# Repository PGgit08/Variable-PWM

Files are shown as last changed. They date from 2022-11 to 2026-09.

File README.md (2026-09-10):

# Variable-PWM
A printed circuit board that generates a PWM signal.

## Description
### How It Works (and Specs)
Variable-PWM is a PCB that generates a PWM signal. It was designed with [Autodesk Eagle](https://www.autodesk.com/products/eagle/overview?term=1-YEAR&tab=subscription) and manufactured by [JLCPCB](https://jlcpcb.com/). It produces a pulse width modulation (PWM) square-wave signal. This signal can be modified with potentiometers **VR1** and **VR2**. **VR1** changes the signal's *frequency*, which can either range from around **0.7 HZ - 7 HZ (SLOW MODE)** or **19.7 HZ - 216.7 HZ (FAST MODE)**. Switch **S1** sets the board to **FAST MODE** if it is switched to the *left*, and it sets the board to **SLOW MODE** if it is switched to the *right*. Potentiometer **VR2** controls the signal's *duty cycle* which ranges from **0% - ~100%**. LED **D1** indicates the signal produced by the board by flashing on and off depending on the signal. **[Click here for an in-depth explanation.](/Docs/Explanation.md)**

### Board Images (Front and Back)
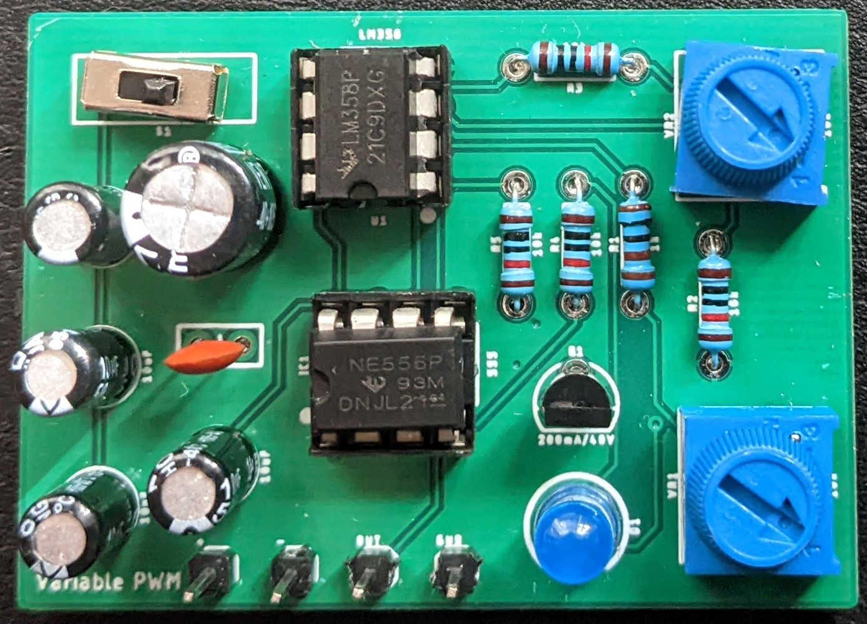
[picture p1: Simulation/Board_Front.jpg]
Board Front

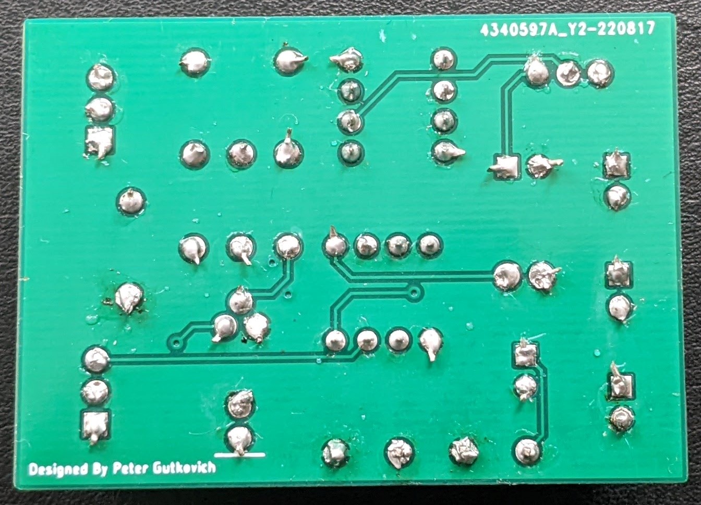
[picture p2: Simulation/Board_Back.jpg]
Board Back


## How To Use the Board
**The board should be powered with a 9V Battery.** Use the **+** and **-** pins to power the board. Use the **OUT** pin for the output signal, and the **GND** pin for connecting to the *board's* ground. Information on how to use the switch and potentiometers can be found **[here](https://github.com/PGgit08/Variable-PWM#how-it-works)**. Click **[here](/Simulation/SimVideos.md)** to see this board in action. 

## Design and Parts
### Design Hardware
The schematic and board files can be found in **[the Hardware folder](/Hardware)**. Gerber files for production are in **[this](/Production/Variable_PWM.zip)** zip folder. Also, an image of the schematic can also be seen right **[here](/Hardware/Variable_PWM.pdf)**.

### Parts Required
- LM358P Dual Operational Amplifier DIP-8 **(x1)** -> [Amazon Link](https://www.amazon.com/gp/product/B07WQWPLSP/)
- NE555 Timer DIP-8 **(x1)** -> [Amazon Link](https://www.amazon.com/gp/product/B07WR9B4JT)
- 10 uF Electrolytic Capacitor @50V (Generic) **(x4)**
- 100 uF Electrolytic Capacitor @50V (Generic) **(x1)**
- 0.1 uF Ceramic Capacitor @>9V (Generic) **(x1)**
- 10K Potentiometer **(x2)** -> [SparkFun Link](https://www.sparkfun.com/products/9806)
- DIP-8 IC Socket **(x2)** -> [SparkFun Link](https://www.sparkfun.com/products/7937)
- 10K Resistor (Generic) **(x4)** 
- 1K Resistor (Generic) **(x4)** 
- 3 Pin Slideswitch **(x1)** -> [Amazon Link](https://www.amazon.com/gp/product/B09R42XQTB)
- Male Header Pin (Generic) **(x4)**
- NPN Transistor @200mA/40V (Generic) **(x1)**
- LED @3V (Generic) **(x1)**

### **SCHEMATIC BASED ON SPARKFUN LIBRARIES -> [HERE](https://github.com/sparkfun/SparkFun-Eagle-Libraries)**

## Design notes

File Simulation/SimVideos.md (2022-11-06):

# Some Videos of the Board in Action
## **[Board Solo](https://photos.google.com/share/AF1QipOQt86xYu3LIYoZ4iMx8fBLORTxNIkFSiyrlg-VXAM1FTR-PDyvdi02ja0fbHQabA/photo/AF1QipOMZab4ttYgHVCj0UGzJjJedmy8gmi2GRmviDpl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)**
## **[Board Output Connected to NOT Gate](https://photos.google.com/share/AF1QipOQt86xYu3LIYoZ4iMx8fBLORTxNIkFSiyrlg-VXAM1FTR-PDyvdi02ja0fbHQabA/photo/AF1QipPCAgb7WWB-7l3uK8WQgtHVEI_uT10_1KNGCgFk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)**

### **NOTE: When board is in FAST MODE it looks strange in the video because the signal frequency is close to the camera's framerate**

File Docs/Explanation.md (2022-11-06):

# Variable PWM In-Depth Explanation (HAND WRITTEN)
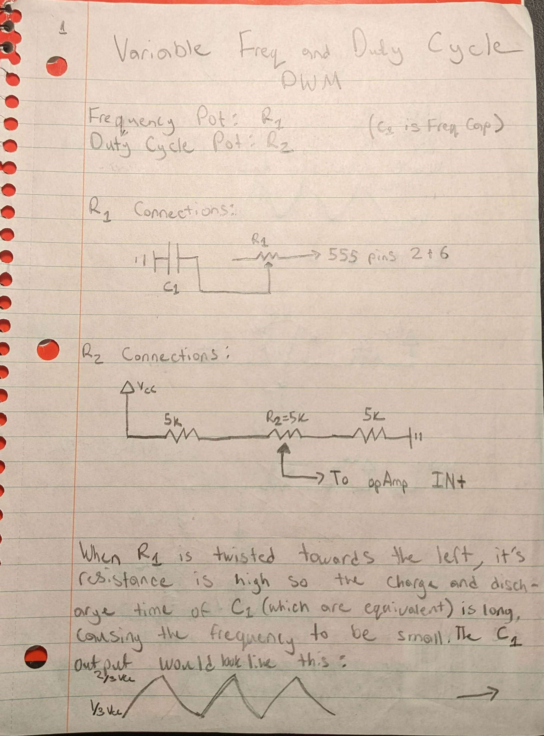
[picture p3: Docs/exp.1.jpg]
Page 1

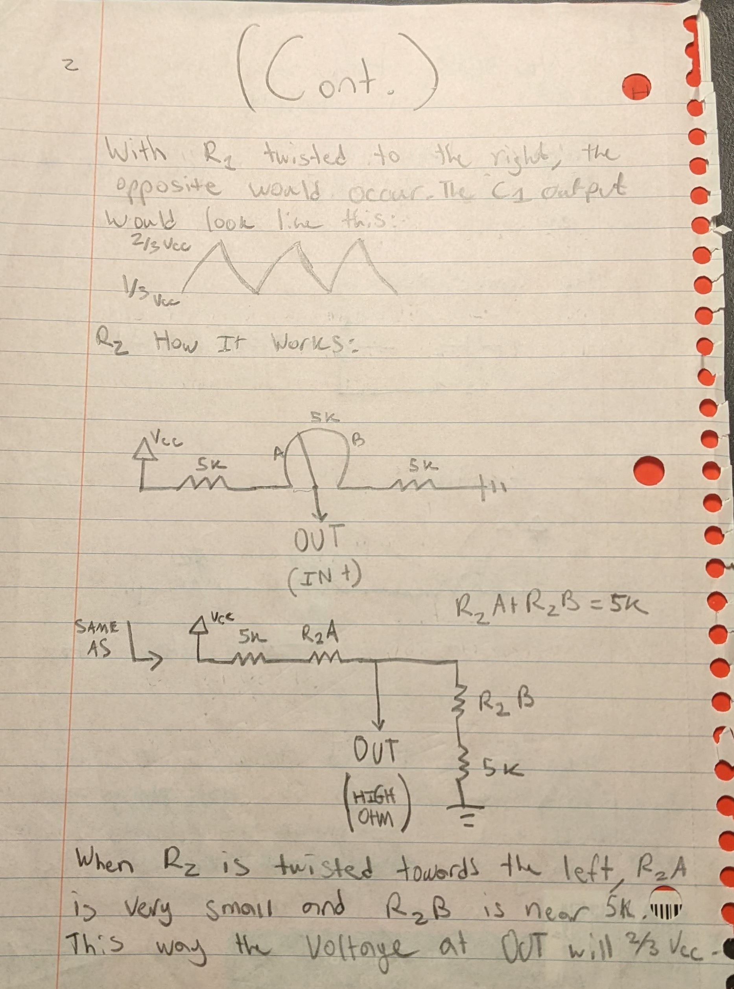
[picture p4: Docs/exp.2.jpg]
Page 2

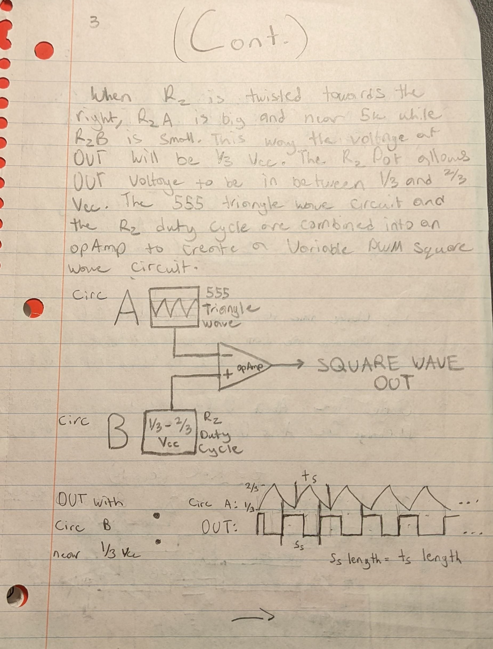
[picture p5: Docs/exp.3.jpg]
Page 3

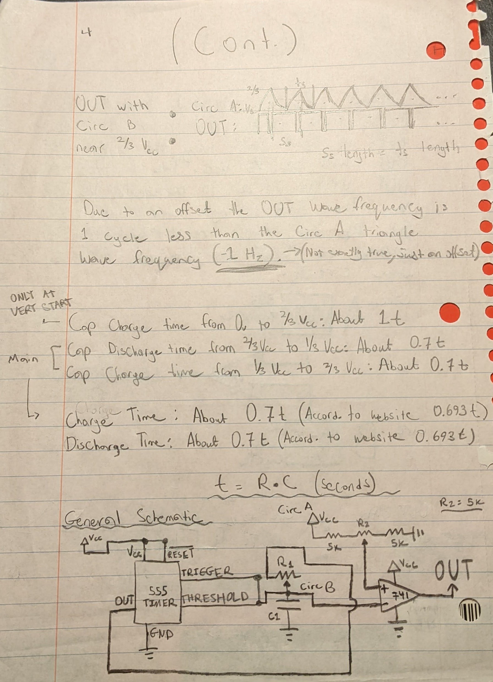
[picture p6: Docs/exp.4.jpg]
Page 4


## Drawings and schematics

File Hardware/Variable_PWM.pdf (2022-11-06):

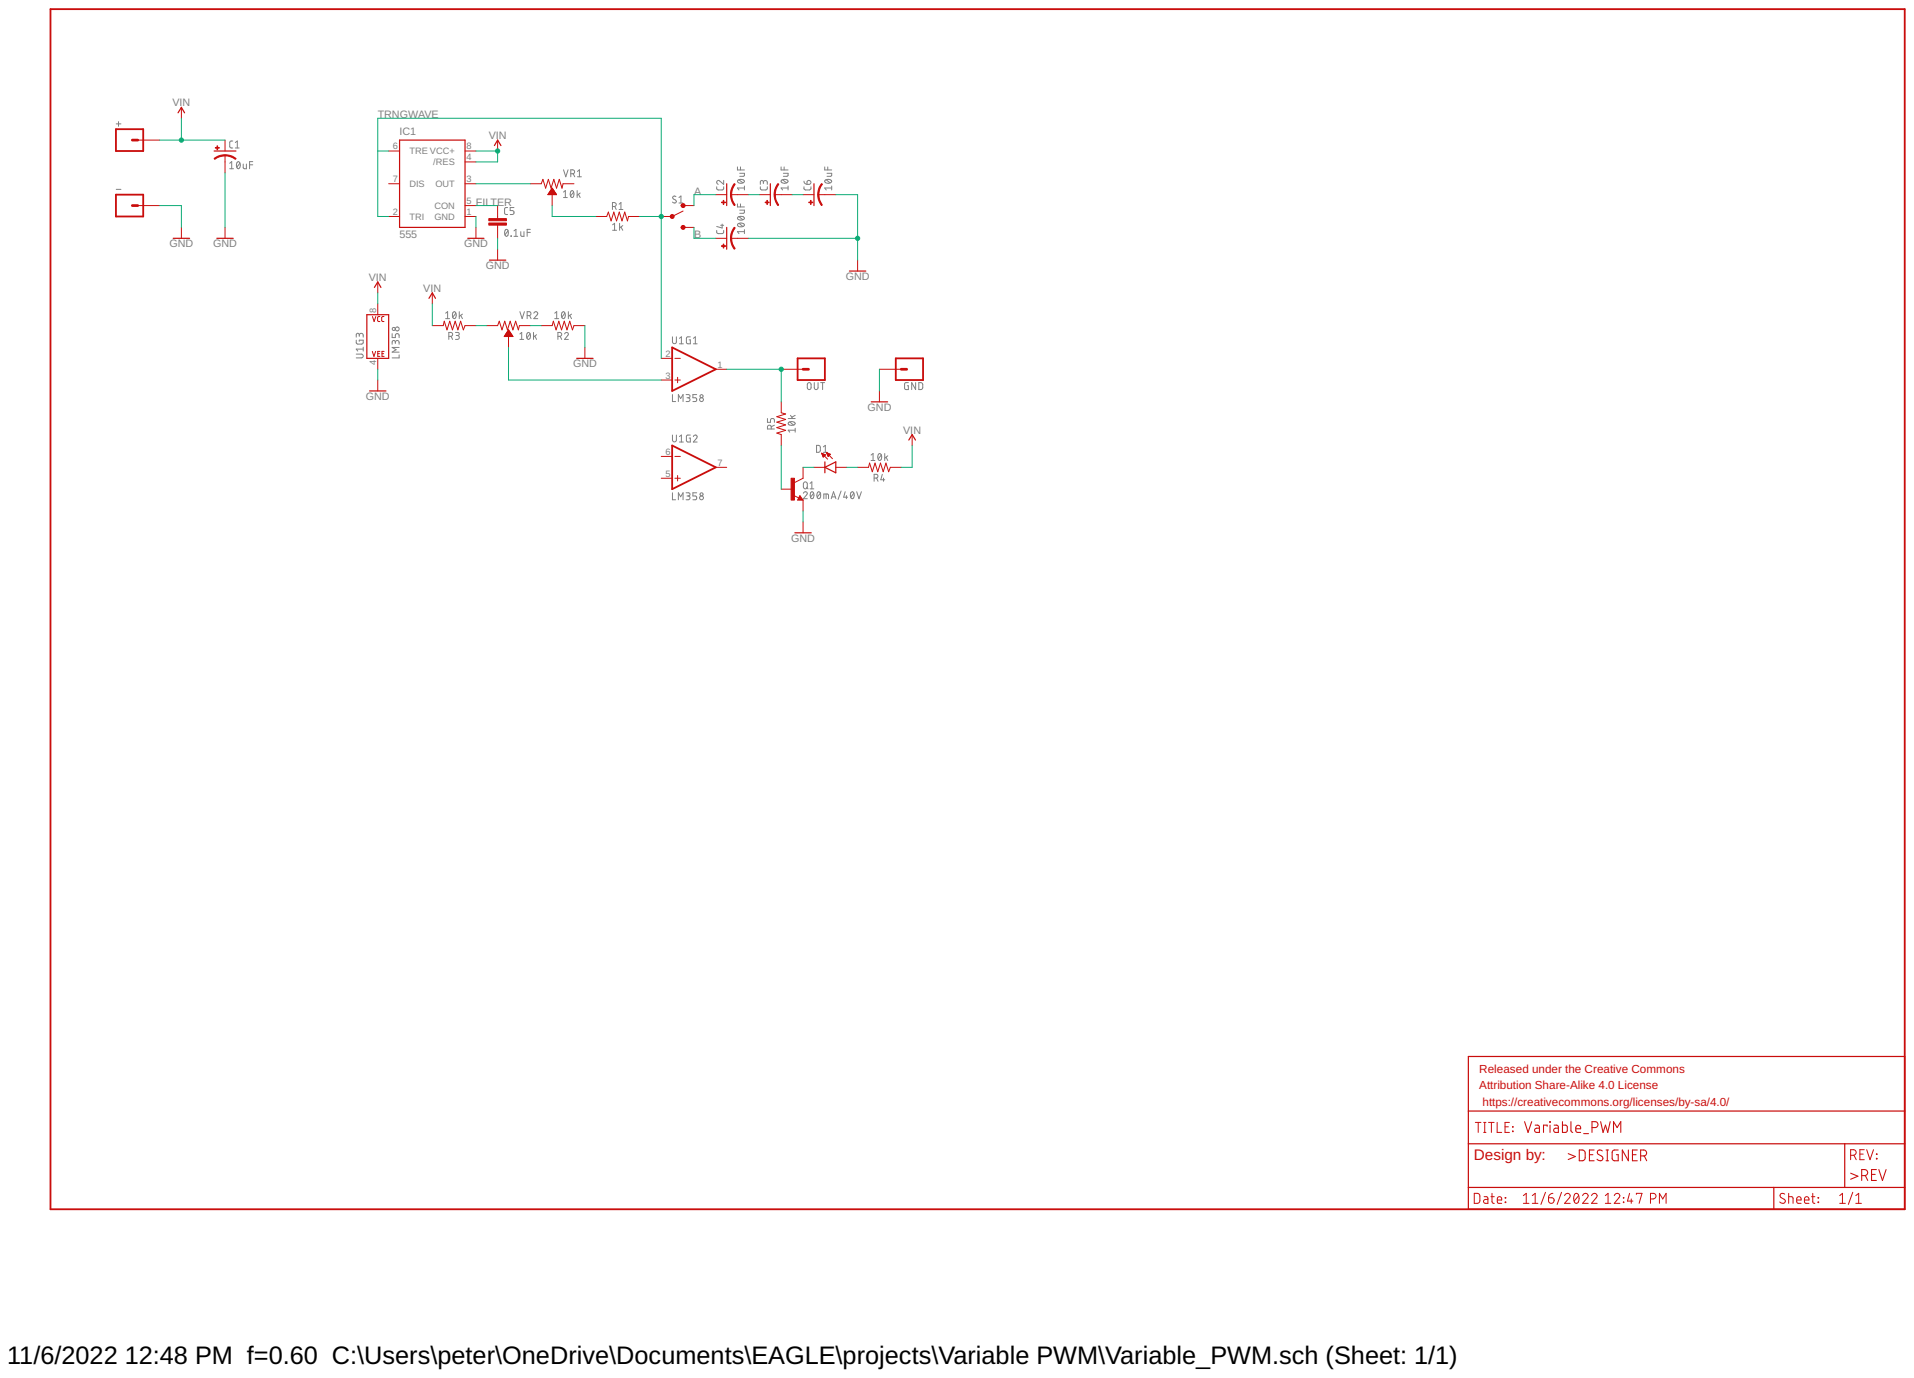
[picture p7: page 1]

Released under the Creative Commons Attribution Share-Alike 4.0 License

https://creativecommons.org/licenses/by-sa/4.0/ Design by:

11/6/2022 12:48 PM f=0.60 C:\Users\peter\OneDrive\Documents\EAGLE\projects\Variable PWM\Variable_PWM.sch (Sheet: 1/1)

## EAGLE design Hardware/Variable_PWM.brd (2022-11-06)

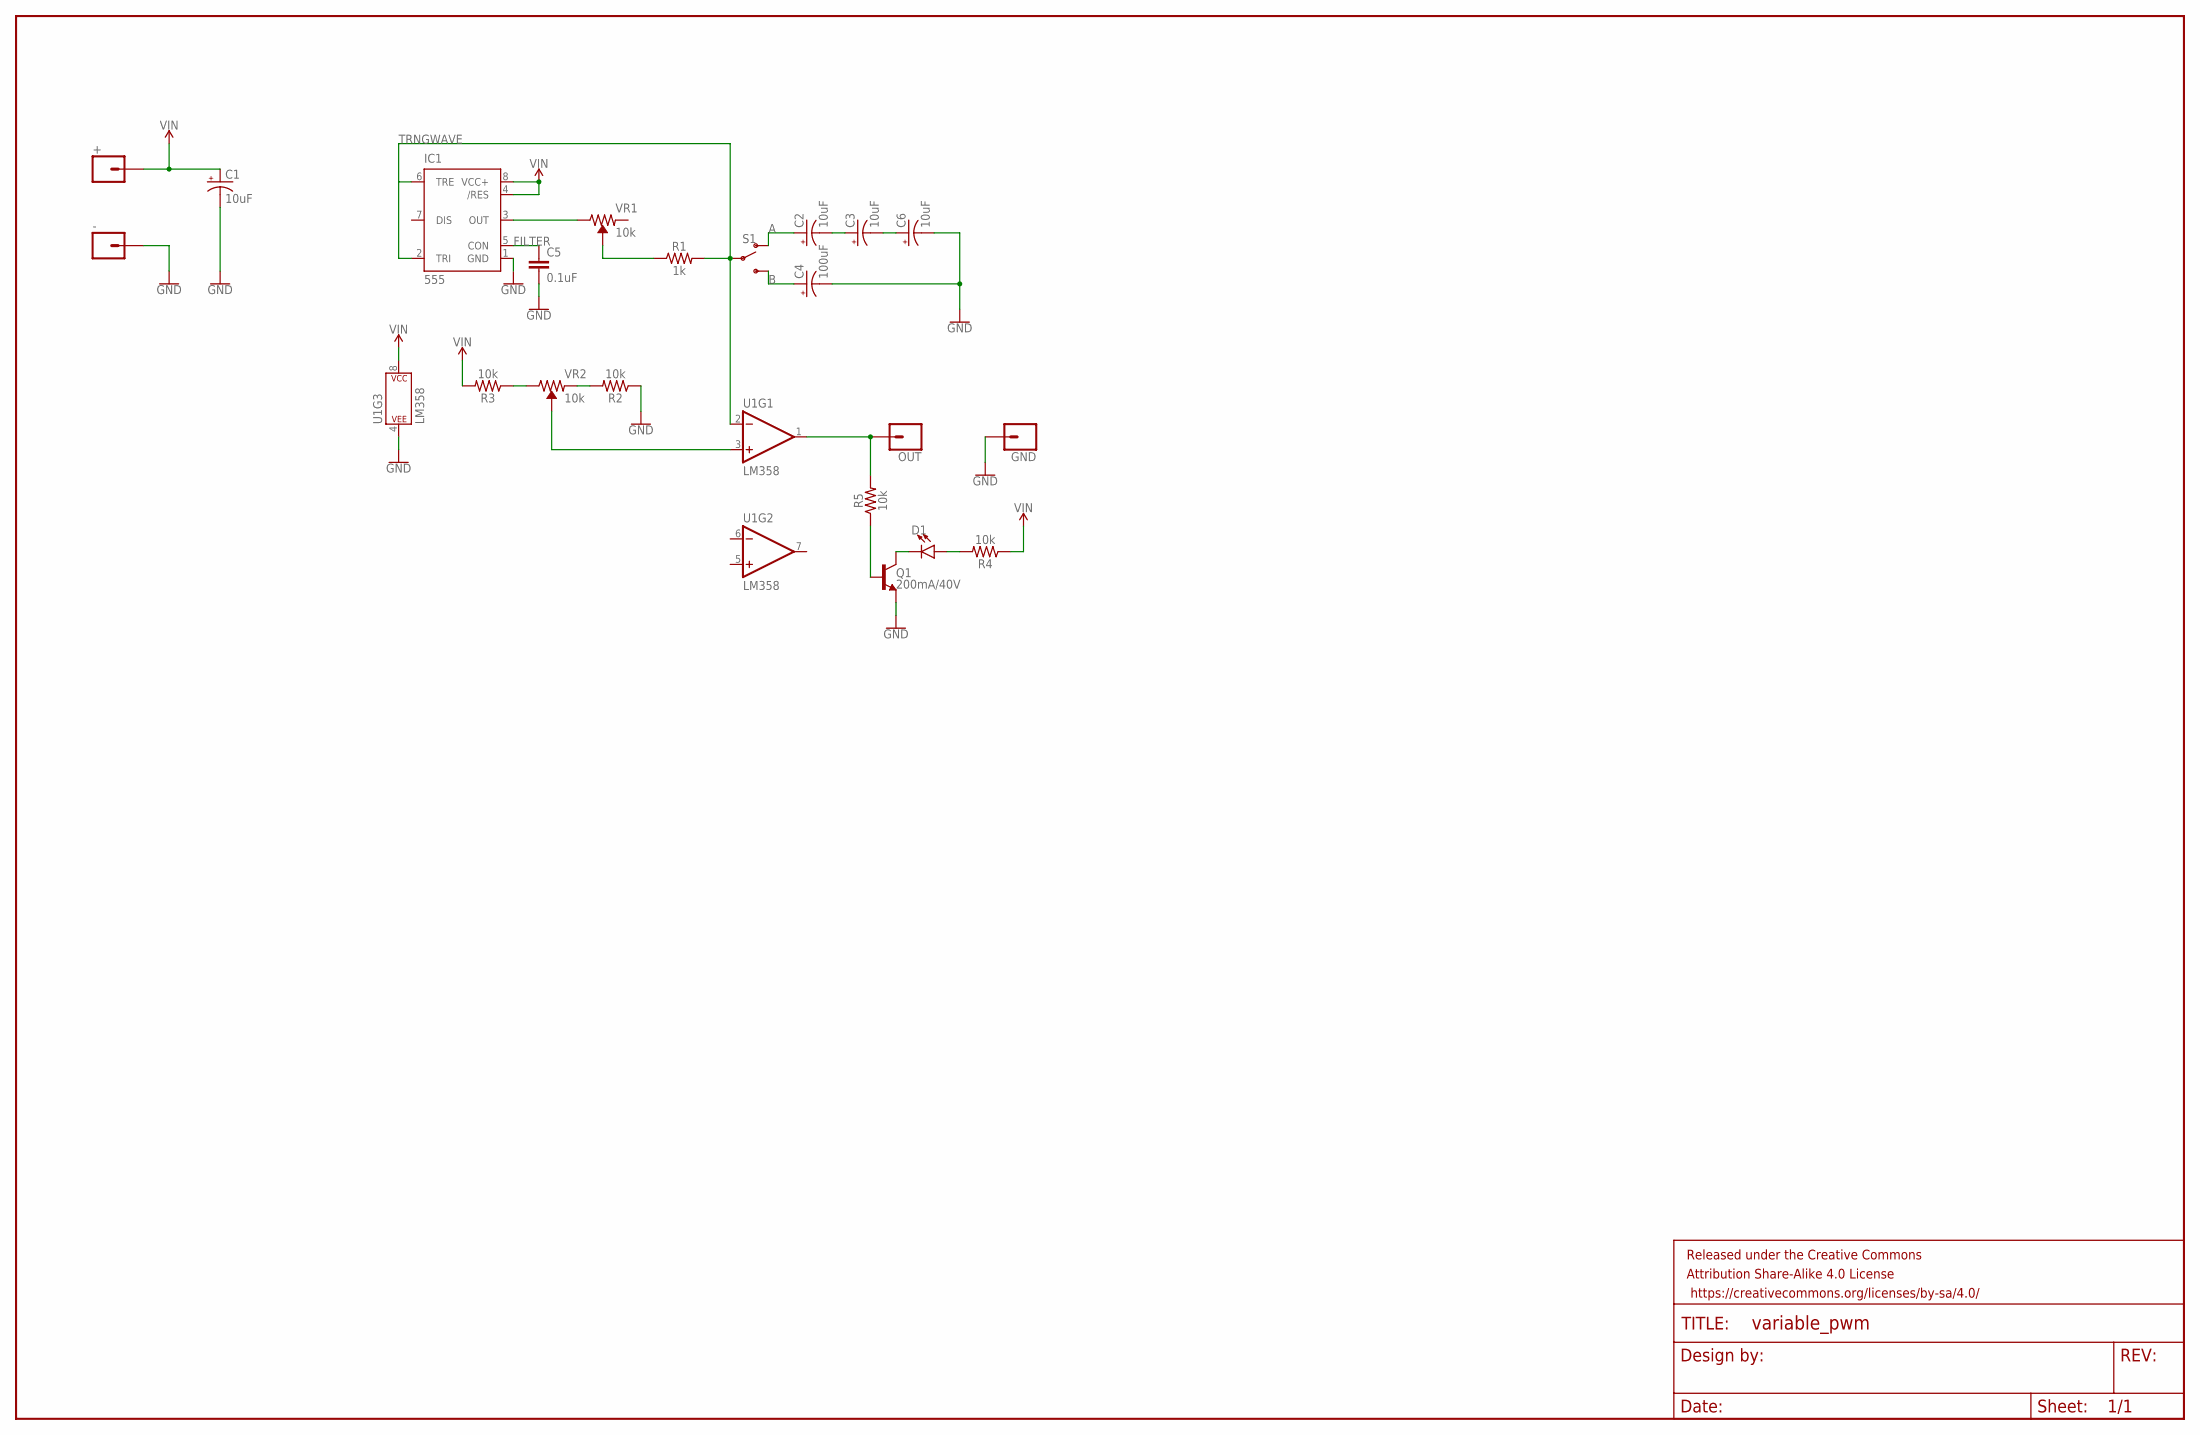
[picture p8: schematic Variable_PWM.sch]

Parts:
+: CONN_01; 1X01
-: CONN_01; 1X01
C1, C2, C3, C6: 10uF; CPOL-RADIAL-2.5MM-5MM
C4: 100uF; CPOL-RADIAL-2.5MM-6.5MM
C5: 0.1uF; CAP-PTH-SMALL-KIT
D1: LED5MM; LED_5MM
FRAME1: FRAME-LEDGERNO_FOOTPRINT; DUMMY
GND: CONN_01; 1X01
IC1: 555; DIP08
OUT: CONN_01; 1X01
Q1: 200mA/40V; TO-92
R1: 1k; AXIAL-0.3
R2, R3, R4, R5: 10k; AXIAL-0.3
S1: SWITCH-SPDT-PTH-11.6X4.0MM; SWITCH_SPDT_PTH_11.6X4.0MM
U1: LM358; DIP08
VR1, VR2: 10k; TRIMPOT-PTH-3386U

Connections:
A: C2.1 (+), S1.1 (O)
B: C4.1 (+), S1.3 (S)
FILTER: C5.1, IC1.5 (CON)
GND: -.1, C1.2 (-), C4.2 (-), C5.2, C6.2 (-), GND.1, IC1.1 (GND), Q1.1 (E), R2.P$1 (1), U1.4 (P$V-)
unnamed: C2.2 (-), C3.1 (+)
unnamed: C3.2 (-), C6.1 (+)
unnamed: R1.P$1 (1), VR1.2 (WIPER)
unnamed: IC1.3 (OUT), VR1.3 (CW)
unnamed: R2.P$2 (2), VR2.1 (CCW)
unnamed: R3.P$1 (1), VR2.3 (CW)
unnamed: U1.3 (+IN), VR2.2 (WIPER)
unnamed: D1.A, R4.P$2 (2)
unnamed: D1.K (C), Q1.3 (C)
unnamed: Q1.2 (B), R5.P$1 (1)
OUT: OUT.1, R5.P$2 (2), U1.1 (OUT)
TRNGWAVE: IC1.2 (TRI), IC1.6 (TRE), R1.P$2 (2), S1.2, U1.2 (-IN)
VIN: +.1, C1.1 (+), IC1.4 (/RES), IC1.8 (VCC+), R3.P$2 (2), R4.P$1 (1), U1.8 (P$V+)

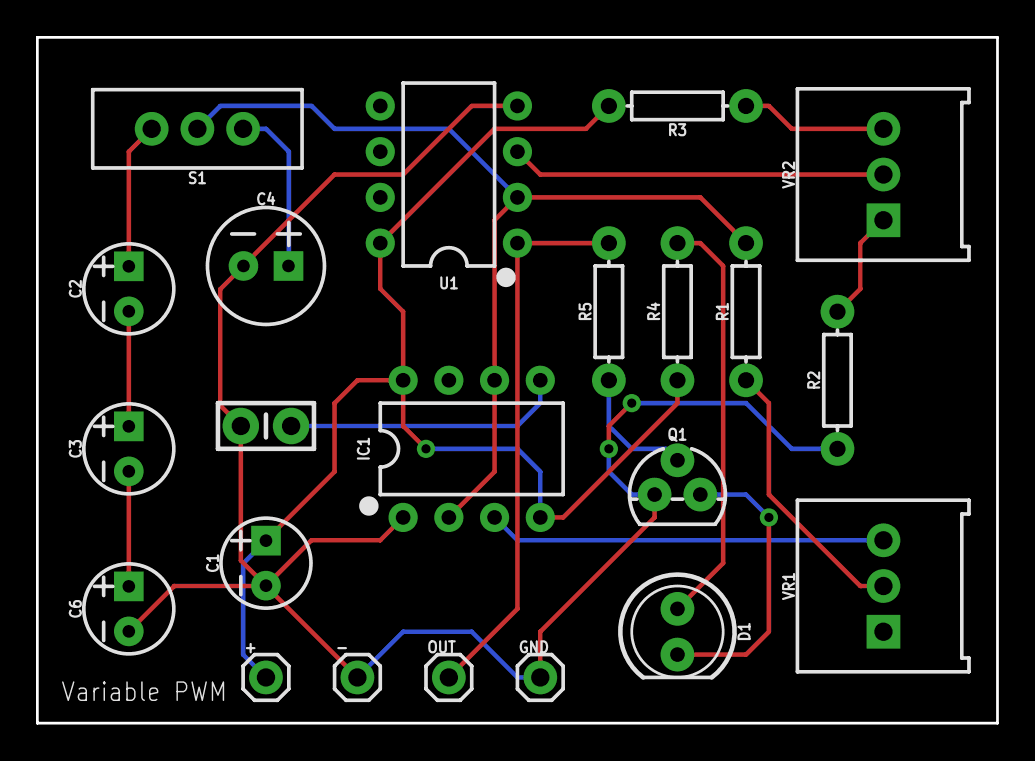
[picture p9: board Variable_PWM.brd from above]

Board: 2 copper layers, 53.3 x 38.1 mm, 23 parts (0 on the bottom side), 17 nets.

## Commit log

2022-11-06 added hardware and production files
    [Variable_PWM.brd, Variable_PWM.sch]
2022-11-06 added SVG image of schematic
2022-11-06 added pdf image of schematic
2022-11-13 pcb images changed

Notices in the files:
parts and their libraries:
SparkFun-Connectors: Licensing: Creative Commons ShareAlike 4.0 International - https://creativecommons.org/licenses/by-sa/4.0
